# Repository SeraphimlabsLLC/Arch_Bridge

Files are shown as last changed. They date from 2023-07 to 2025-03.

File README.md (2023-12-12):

# Arch_Bridge

DCC-EX to Loconet accessory bus interface with throttle and booster driving. 

Additional 2A booster channel for future use

 Bidirectional transmission of turnout commands from Loconet to DCC-EX
 One way Throttle transmission, Loconet to DCC-EX

 Fastclock supplied to DCC-EX, still WIP getting it on Loconet

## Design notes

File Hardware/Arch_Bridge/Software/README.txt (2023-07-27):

TTY Pin Map
TXD = GPIO43(U0TXD)
RXD = GPIO44(U0RXD)

I2C Pin Map
SDA = GPIO15
SCL = GPIO16

Loconet Pin Map
LN_TX = GPIO17(U1RXD)
LN_RX = GPIO18 (U1RXD)
LN_COLL = GPIO0

Railsync input Pin Map
RSYNC_IN = GPIO9

Railsync output Pin Map
ENA_10 = GPIO10
DCC_1 = GPIO11
BRK_1 = GPIO12
ENA_1i = GPIO13
SNS1 = GPIO1(ADC1_CH0)

Track output Pin Map
ENA_20 = GPIO14
DCC_2 = GPIO21
BRK_2 = GPIO47
ENA_2i = GPIO48
SNS2 = GPIO2(ADC1_CH1)

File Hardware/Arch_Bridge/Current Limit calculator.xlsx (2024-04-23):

A | 0.2 | 0.2 | 0.2 | A | 2 | 2 | 2
SF (A per A) | 0.0015 | 0.0015 | 0.0015 | SF (A per A) | 0.0015 | 0.0015 | 0.0015
% | 0.10% |  | 0.10% | % | 0.10% |  | 0.10%
Ipropi(A) | 0.0003 | 0.0003 | 0.0003 | Ipropi(A) | 0.003 | 0.003 | 0.003
Ripropi(oh) | 9090.9 | 9100 | 9109.1 | Ripropi(oh) | 909.09 | 910 | 910.91
Vipropi(V) | 2.72727 | 2.73 | 2.73273 | Vipropi(V) | 2.72727 | 2.73 | 2.73273
vref | 3.3 | 3.3 | 3.3 | vref | 3.3 | 3.3 | 3.3
itripprpi | 0.000363000363 | 0.0003626373626 | 0.0003622750875 | itripprpi | 0.00363000363 | 0.003626373626 | 0.003622750875
Trip | 0.242000242 | 0.2417582418 | 0.241516725 | Trip | 2.42000242 | 2.417582418 | 2.41516725
Trip_Tick | 319.6745132 | 319.3548387 | 319.0358029 |  | 3196.745132 | 3193.548387 | 3190.358029
Vmax | 3.1 | 3.1 | 3.1 | Vmax | 3.1 | 3.1 | 3.1
Dmax | 4095 | 4095 | 4095 | Dmax | 4095 | 4095 | 4095
Div/V | 1320.967742 | 1320.967742 | 1320.967742 | Div/V | 1320.967742 | 1320.967742 | 1320.967742
Div/A | 16921.47068 | 16938.40909 | 16955.3475 | Div/A | 1692.147068 | 1693.840909 | 1695.53475
div/mA | 16.92147068 | 16.93840909 | 16.9553475 | Div/mA | 1.692147068 | 1.693840909 | 1.69553475
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

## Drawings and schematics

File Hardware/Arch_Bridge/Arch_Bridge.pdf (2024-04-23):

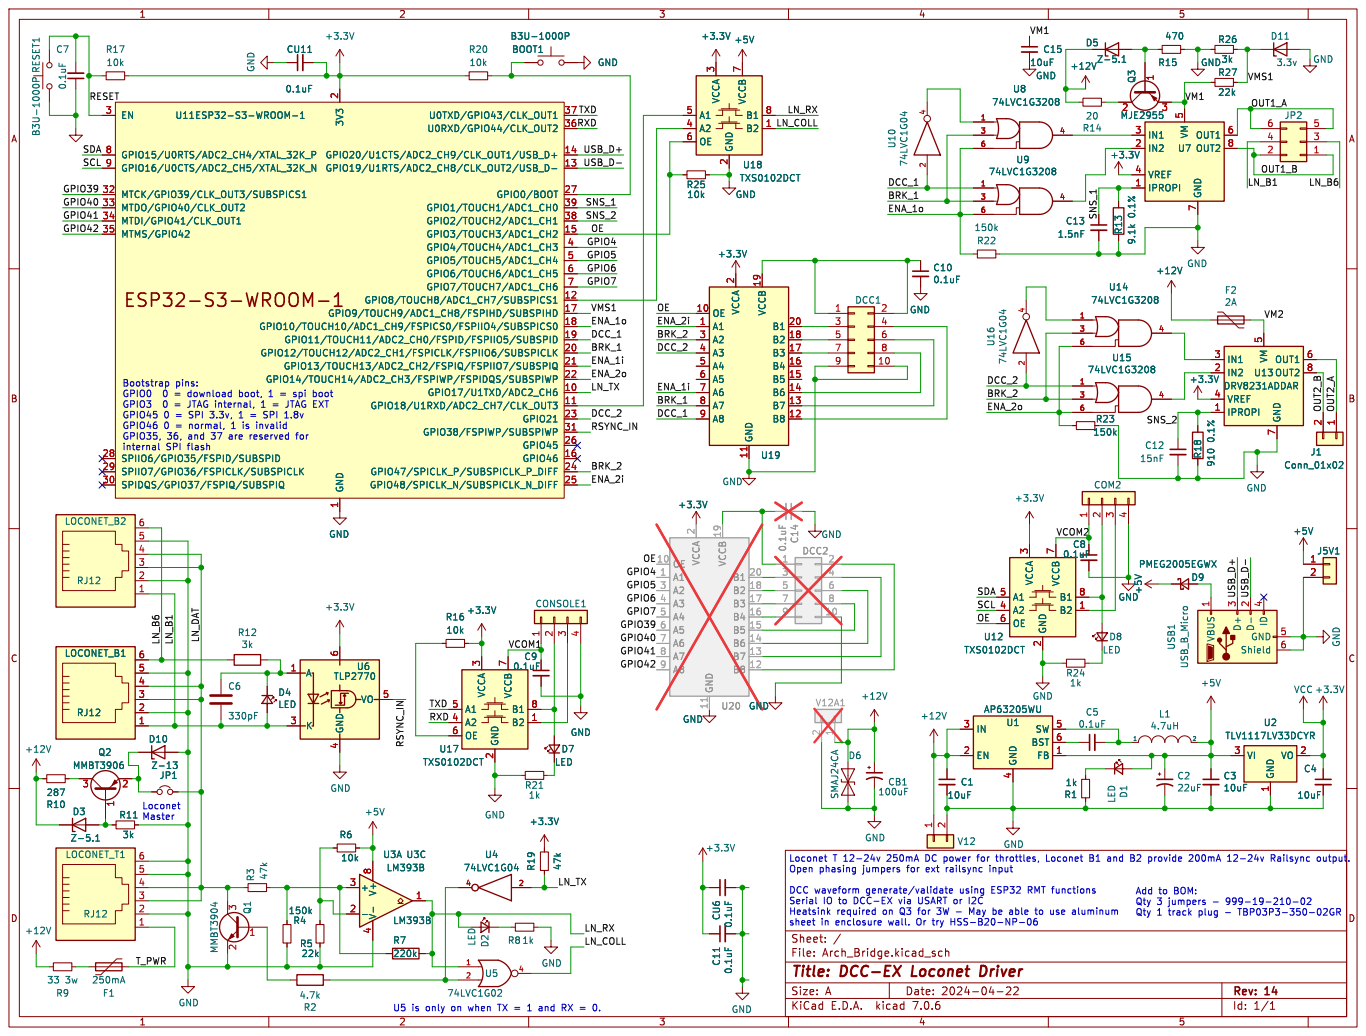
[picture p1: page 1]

2 GPIO12/TOUCH12/ADC2_CH1/FSPICLK/FSPIIO6/SUBSPICLK 20 GPIO13/TOUCH13/ADC2_CH2/FSPIQ/FSPIIO7/SUBSPIQ 21 GPIO14/TOUCH14/ADC2_CH3/FSPIWP/FSPIDQS/SUBSPIWP 22 GPIO21 23 GPIO47/SPICLK_P/SUBSPICLK_P_DIFF 24 GPIO48/SPICLK_N/SUBSPICLK_N_DIFF 25 GPIO45 26 GPIO0/BOOT 27 SPIIO6/GPIO35/FSPID/SUBSPID 28 SPIIO7/GPIO36/FSPICLK/SUBSPICLK 29 EN 3 SPIDQS/GPIO37/FSPIQ/SUBSPIQ 30 GPIO38/FSPIWP/SUBSPIWP 31 MTCK/GPIO39/CLK_OUT3/SUBSPICS1 32 MTDO/GPIO40/CLK_OUT2 33 MTDI/GPIO41/CLK_OUT1 34 MTMS/GPIO42 35 U0RXD/GPIO44/CLK_OUT2 36 U0TXD/GPIO43/CLK_OUT1 37 GPIO2/TOUCH2/ADC1_CH1 38 GPIO1/TOUCH1/ADC1_CH0 39 GPIO4/TOUCH4/ADC1_CH3 4 GPIO5/TOUCH5/ADC1_CH4 5 GPIO6/TOUCH6/ADC1_CH5 6 GPIO7/TOUCH7/ADC1_CH6 7 GPIO15/U0RTS/ADC2_CH4/XTAL_32K_P 8 GPIO16/U0CTS/ADC2_CH5/XTAL_32K_N 9 CU11

7 B1 8U19 A1 1 OE 10 GND 11 B8 12 B7 13 B6 14 B5 15 B4 16 B3 17 B2 18 VCCB 19 VCCA

2 GPIO12/TOUCH12/ADC2_CH1/FSPICLK/FSPIIO6/SUBSPICLK 20 GPIO13/TOUCH13/ADC2_CH2/FSPIQ/FSPIIO7/SUBSPIQ 21 GPIO14/TOUCH14/ADC2_CH3/FSPIWP/FSPIDQS/SUBSPIWP 22 GPIO21 23 GPIO47/SPICLK_P/SUBSPICLK_P_DIFF 24 GPIO48/SPICLK_N/SUBSPICLK_N_DIFF 25 GPIO45 26 GPIO0/BOOT 27 SPIIO6/GPIO35/FSPID/SUBSPID 28 SPIIO7/GPIO36/FSPICLK/SUBSPICLK 29 EN 3 SPIDQS/GPIO37/FSPIQ/SUBSPIQ 30 GPIO38/FSPIWP/SUBSPIWP 31 MTCK/GPIO39/CLK_OUT3/SUBSPICS1 32 MTDO/GPIO40/CLK_OUT2 33 MTDI/GPIO41/CLK_OUT1 34 MTMS/GPIO42 35 U0RXD/GPIO44/CLK_OUT2 36 U0TXD/GPIO43/CLK_OUT1 37 GPIO2/TOUCH2/ADC1_CH1 38 GPIO1/TOUCH1/ADC1_CH0 39 GPIO4/TOUCH4/ADC1_CH3 4 GPIO5/TOUCH5/ADC1_CH4 5 GPIO6/TOUCH6/ADC1_CH5 6 GPIO7/TOUCH7/ADC1_CH6 7 GPIO15/U0RTS/ADC2_CH4/XTAL_32K_P 8 GPIO16/U0CTS/ADC2_CH5/XTAL_32K_N 9 U11 ESP32-S3-WROOM-1 A

1 GPIO17/U1TXD/ADC2_CH6 10 GPIO18/U1RXD/ADC2_CH7/CLK_OUT3 11 GPIO8/TOUCH8/ADC1_CH7/SUBSPICS1 12 GPIO19/U1RTS/ADC2_CH8/CLK_OUT2/USB_D- 13 GPIO20/U1CTS/ADC2_CH9/CLK_OUT1/USB_D+ 14 GPIO3/TOUCH3/ADC1_CH2 15 GPIO46 16 GPIO9/TOUCH9/ADC1_CH8/FSPIHD/SUBSPIHD 17 GPIO10/TOUCH10/ADC1_CH9/FSPICS0/FSPIIO4/SUBSPICS0 18 GPIO11/TOUCH11/ADC2_CH0/FSPID/FSPIIO5/SUBSPID 19 3V3

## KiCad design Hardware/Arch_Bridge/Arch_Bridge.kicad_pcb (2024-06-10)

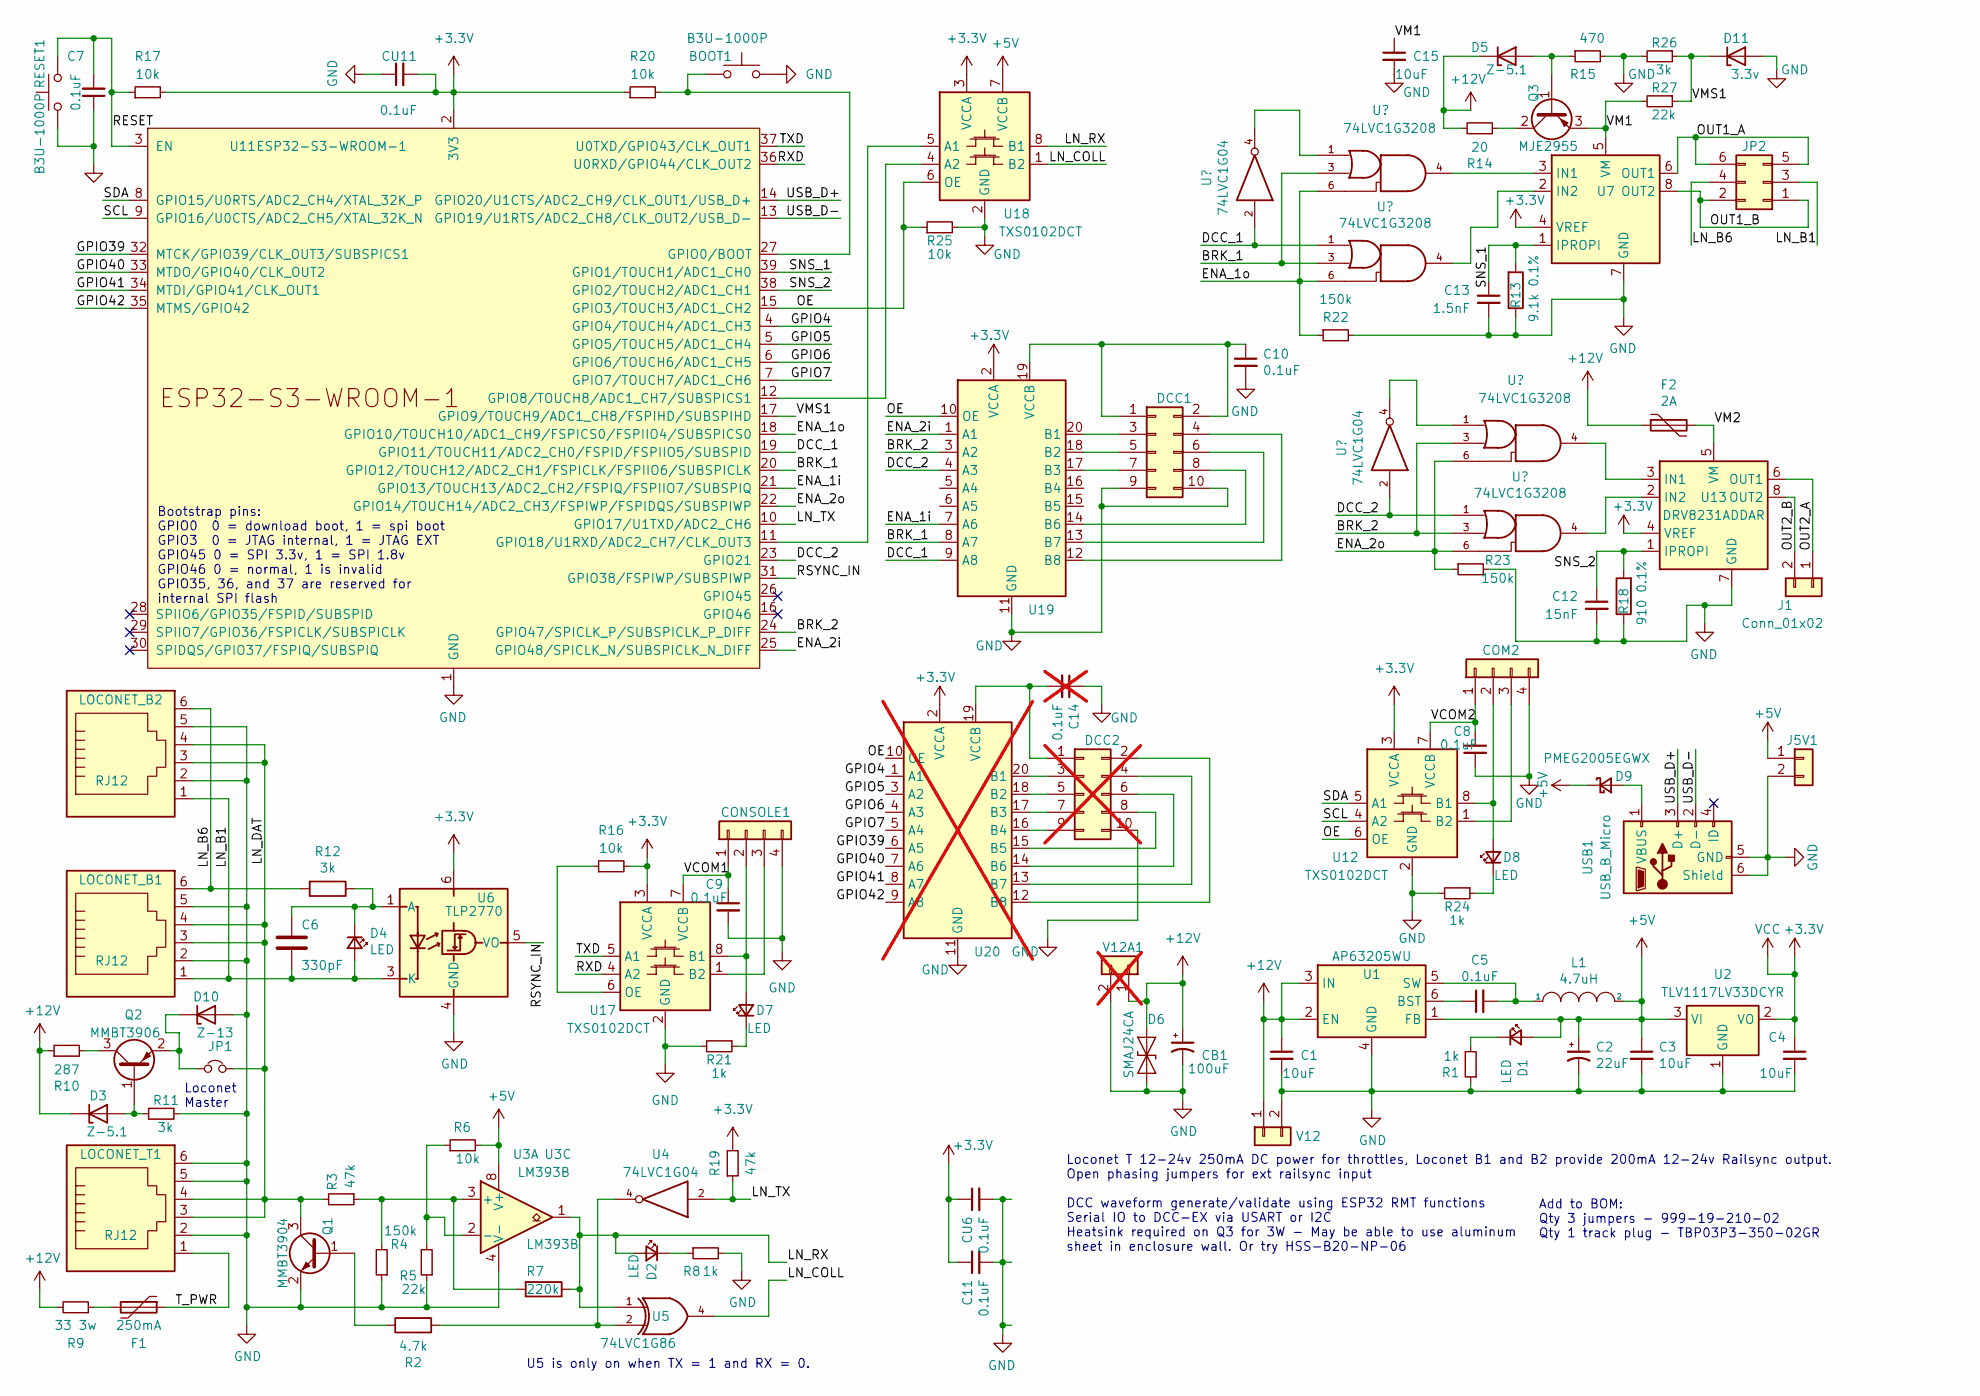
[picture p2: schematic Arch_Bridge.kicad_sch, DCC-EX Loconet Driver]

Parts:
BOOT1: B3U-1000P; SW_SPST_B3U-1000P-B; LCSC SKU C231329
C1, C3, C4, C15: 10uF; C_1210_3225Metric; LCSC SKU C380537
C2: 22uF; CP_Elec_5x5.3; LCSC SKU C2164091
C5, C7, C8, C9, C10, C11: 0.1uF; C_1206_3216Metric; LCSC SKU C600013
C6: 330pF; C_1206_3216Metric; LCSC SKU C2223641
C12: 15nF; C_1206_3216Metric_Pad1.33x1.80mm_HandSolder; LCSC SKU C2174116
C13: 1.5nF; C_1206_3216Metric_Pad1.33x1.80mm_HandSolder; LCSC SKU C2230319
C14: 0.1uF; C_1206_3216Metric; LCSC SKU C600013; not fitted
CB1: 100uF; CP_Elec_8x10; LCSC SKU C696384
COM2: Conn_01x04; PinSocket_1x04_P2.54mm_Vertical; LCSC SKU C3323964
CONSOLE1: Conn_01x04; PinSocket_1x04_P2.54mm_Vertical; LCSC SKU C3323964
CU6, CU11: 0.1uF; C_1206_3216Metric; LCSC SKU C600013
D1, D2, D4, D7, D8: LED; LED_1206_3216Metric
D3, D5: Z-5.1; D_MiniMELF; LCSC SKU C550442
D6: SMAJ24CA; D_SMA; LCSC SKU C148223
D9: PMEG2005EGWX; D_SOD-123; LCSC SKU C552812
D10: Z-13; D_MiniMELF; LCSC SKU C550391
D11: 3.3v; D_MiniMELF; LCSC SKU C550442
DCC1: Conn_02x05_Odd_Even; PinSocket_2x05_P2.54mm_Vertical; LCSC SKU C6235491
DCC2: Conn_02x05_Odd_Even; PinSocket_2x05_P2.54mm_Vertical; LCSC SKU C6235491; not fitted
F1: 250mA; Fuse_1206_3216Metric; LCSC SKU C2442492
F2: 2A; Fuse_Bourns_MF-RHT200; LCSC SKU C2153889
J1: Conn_01x02; PhoenixContact_MC_1,5_2-G-3.5_1x02_P3.50mm_Horizontal; LCSC SKU C880572
J5V1: Conn_01x02; PinSocket_1x02_P2.54mm_Vertical; LCSC SKU C3323491
JP1: Jumper_NC_Small; PinHeader_1x02_P2.54mm_Vertical; LCSC SKU C5172712
JP2: Conn_02x03_Odd_Even; PinHeader_2x03_P2.54mm_Vertical; LCSC SKU C6360273
L1: 4.7uH; L_Wurth_WE-LQSH-4020; LCSC SKU C167828
LOCONET_B1, LOCONET_B2: RJ12; RJ12_Amphenol_54601; LCSC SKU C4355015
LOCONET_T1: RJ12; RJ12_Amphenol_54601; LCSC SKU C4355015
Q1: MMBT3904; SOT-23; LCSC SKU C77991
Q2: MMBT3906; SOT-23; LCSC SKU C77990
Q3: MJE2955; TO-220-3_Vertical; LCSC SKU C184196
R1, R8, R21, R24: 1k; R_1206_3216Metric; LCSC SKU C131398
R2: 4.7k; R_1206_3216Metric; LCSC SKU C3975500
R3, R19: 47k; R_1206_3216Metric; LCSC SKU C137270
R4, R22, R23: 150k; R_1206_3216Metric; LCSC SKU C114931
R5, R27: 22k; R_1206_3216Metric; LCSC SKU C114942
R6, R16, R17, R20, R25: 10k; R_1206_3216Metric; LCSC SKU C4303232
R7: 220k; R_1206_3216Metric; LCSC SKU C130275
R9: 33 3w; R_Axial_DIN0516_L15.5mm_D5.0mm_P5.08mm_Vertical; LCSC SKU C1761032
R10: 287; R_1206_3216Metric; LCSC SKU C488764
R11, R12, R26: 3k; R_1206_3216Metric; LCSC SKU C132648
R13: 9.1k 0.1%; R_1206_3216Metric; LCSC SKU C706423
R14: 20; R_2512_6332Metric; LCSC SKU C309605
R15: 470; R_2512_6332Metric; LCSC SKU C872782
R18: 910 0.1%; R_1206_3216Metric; LCSC SKU C870936
RESET1: B3U-1000P; SW_SPST_B3U-1000P-B; LCSC SKU C231329
U1: AP63205WU; TSOT-23-6; LCSC SKU C2071056
U2: TLV1117LV33DCYR; SOT-223-3_TabPin2; LCSC SKU C91728
U3: LM393B; SOIC-8_3.9x4.9mm_P1.27mm; LCSC SKU C2865059
U4, U10, U16: 74LVC1G04; SOT-23-5_HandSoldering; LCSC SKU C7827
U5: 74LVC1G86; SOT-23-5_HandSoldering; LCSC SKU C402161
U6: TLP2770; SO-6L_10x3.84mm_P1.27mm; LCSC SKU C150160
U7, U13: DRV8231ADDAR; Texas_HTSOP-8-1EP_3.9x4.9mm_P1.27mm_EP2.95x4.9mm_Mask2.4x3.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
U8, U9, U14, U15: 74LVC1G3208; SOT-23-6_Handsoldering; LCSC SKU C2682152
U11: ESP32-S3-WROOM-1; ESP32-S3-WROOM-1U; LCSC SKU C2980298
U12, U17, U18: TXS0102DCT; SSOP-8_2.95x2.8mm_P0.65mm; LCSC SKU C2677354
U19: TXB0108PWR; TSSOP-20_4.4x6.5mm_P0.65mm; LCSC SKU C53406
U20: TXB0108PWR; TSSOP-20_4.4x6.5mm_P0.65mm; LCSC SKU C53406; not fitted
USB1: USB_B_Micro; USB_Micro-B_Molex-105017-0001; LCSC SKU C136000
V12: Conn_01x02; PhoenixContact_MSTBA_2,5_2-G_1x02_P5.00mm_Horizontal
V12A1: Conn_01x02; Screw_Terminal_2pin_Multicomp; not fitted

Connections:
+3.3V: C4.1, C11.1, CU6.1, CU11.2, R16.2, R17.2, R19.2, R20.1, U2.2 (VO), U6.6, U7.4 (VREF), U8.5 (VCC), U9.5 (VCC), U10.5 (VCC), U11.2 (3V3), U12.3 (VCCA), U13.4 (VREF), U14.5 (VCC), U15.5 (VCC), U16.5 (VCC), U17.3 (VCCA), U18.3 (VCCA), U19.2 (VCCA), U20.2 (VCCA)
+5V: C2.1, C3.1, D1.2 (A), D9.1 (K), J5V1.1, L1.2, R6.2, U1.1 (FB), U2.3 (VI), U3.8 (V+), U4.5 (+5V), U5.5 (+5V), U18.7 (VCCB)
+12V: C1.1, CB1.1, D3.1 (K), D5.1 (K), D6.1 (A1), F2.1, R9.2, R10.1, R14.2, U1.2 (EN), U1.3 (IN), V12.1, V12A1.1
/BRK_1: U8.3, U9.3, U11.20 (GPIO12/TOUCH12/ADC2_CH1/FSPICLK/FSPIIO6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), U19.8 (A7)
/BRK_2: U11.24 (GPIO47/SPICLK_P/SUBSPICLK_P_DIFF), U14.3, U15.3, U19.3 (A2)
/DCC_1: U9.1, U10.2, U11.19 (GPIO11/TOUCH11/ADC2_CH0/FSPID/FSPIIO5/S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), U19.9 (A8)
/DCC_2: U11.23 (GPIO21), U15.1, U16.2, U19.4 (A3)
/ENA_1i: U11.21 (GPIO13/TOUCH13/ADC2_CH2/FSPIQ/FSPIIO7/S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), U19.7 (A6)
/ENA_1o: R22.1, U8.6, U9.6, U11.18 (GPIO10/TOUCH10/ADC1_CH9/FSPICS0/FSPIIO4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)
/ENA_2i: U11.25 (GPIO48/SPICLK_N/SUBSPICLK_N_DIFF), U19.1 (A1)
/ENA_2o: R23.1, U11.22 (GPIO14/TOUCH14/ADC2_CH3/FSPIWP/FSPIDQS/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), U14.6, U15.6
/GPIO4: U11.4 (GPIO4/TOUCH4/ADC1_CH3), U20.1 (A1)
/GPIO5: U11.5 (GPIO5/TOUCH5/ADC1_CH4), U20.3 (A2)
/GPIO6: U11.6 (GPIO6/TOUCH6/ADC1_CH5), U20.4 (A3)
/GPIO7: U11.7 (GPIO7/TOUCH7/ADC1_CH6), U20.5 (A4)
/GPIO39: U11.32 (MTCK/GPIO39/CLK_OUT3/SUBSPICS1), U20.6 (A5)
/GPIO40: U11.33 (MTDO/GPIO40/CLK_OUT2), U20.7 (A6)
/GPIO41: U11.34 (MTDI/GPIO41/CLK_OUT1), U20.8 (A7)
/GPIO42: U11.35 (MTMS/GPIO42), U20.9 (A8)
/LN_B1: C6.2, D4.2 (A), JP2.3, LOCONET_B1.1, LOCONET_B2.1, U6.3 (K)
/LN_B6: JP2.4, LOCONET_B1.6, LOCONET_B2.6, R12.2
/LN_COLL: U5.4, U18.1 (B2)
/LN_DAT: JP1.2, LOCONET_B1.3, LOCONET_B1.4, LOCONET_B2.3, LOCONET_B2.4, LOCONET_T1.3, LOCONET_T1.4, Q1.3 (C), R3.2
/LN_RX: D2.2 (A), R7.1, U3.1, U5.1, U18.8 (B1)
/LN_TX: R19.1, U4.2, U11.10 (GPIO17/U1TXD/ADC2_CH6)
/OE: R25.1, U11.15 (GPIO3/TOUCH3/ADC1_CH2), U12.6 (OE), U18.6 (OE), U19.10 (OE), U20.10 (OE)
/OUT1_A: JP2.5, JP2.6, U7.6 (OUT1)
/OUT1_B: JP2.1, JP2.2, U7.8 (OUT2)
/OUT2_A: J1.1, U13.6 (OUT1)
/OUT2_B: J1.2, U13.8 (OUT2)
/RESET: C7.2, R17.1, RESET1.2, U11.3 (EN)
/RSYNC_IN: U6.5 (VO), U11.31 (GPIO38/FSPIWP/SUBSPIWP)
/RXD: U11.36 (U0RXD/GPIO44/CLK_OUT2), U17.4 (A2)
/SCL: U11.9 (GPIO16/U0CTS/ADC2_CH5/XTAL_32K_N), U12.4 (A2)
/SDA: U11.8 (GPIO15/U0RTS/ADC2_CH4/XTAL_32K_P), U12.5 (A1)
/SNS_1: C13.1, R13.2, U7.1 (IPROPI), U11.39 (GPIO1/TOUCH1/ADC1_CH0)
/SNS_2: C12.1, R18.2, U11.38 (GPIO2/TOUCH2/ADC1_CH1), U13.1 (IPROPI)
/TXD: U11.37 (U0TXD/GPIO43/CLK_OUT1), U17.5 (A1)
/T_PWR: F1.1, LOCONET_T1.1
/USB_D+: U11.14 (GPIO20/U1CTS/ADC2_CH9/CLK_OUT1/USB_D+), USB1.3 (D+)
/USB_D-: U11.13 (GPIO19/U1RTS/ADC2_CH8/CLK_OUT2/USB_D-), USB1.2 (D-)
/VCOM1: C9.1, CONSOLE1.1, U17.7 (VCCB)
/VCOM2: C8.1, COM2.1, U12.7 (VCCB)
/VM1: C15.1, Q3.3 (E), R27.2, U7.5 (VM)
/VM2: F2.2, U13.5 (VM)
/VMS1: D11.1 (K), R26.1, R27.1, U11.17 (GPIO9/TOUCH9/ADC1_CH8/FSPIHD/SUBSPIHD)
GND: BOOT1.1, C1.2, C2.2, C3.2, C4.2, C7.1, C8.2, C9.2, C10.2, C11.2, C12.2, C13.2, C14.1, C15.2, CB1.2, COM2.4, CONSOLE1.4, CU6.2, CU11.1, D6.2 (A2), D10.2 (A), D11.2 (A), DCC1.9, DCC1.10, DCC2.10, J5V1.2, LOCONET_B1.2, LOCONET_B1.5, LOCONET_B2.2, LOCONET_B2.5, LOCONET_T1.2, LOCONET_T1.5, LOCONET_T1.6, Q1.2 (E), R1.1, R4.1, R5.1, R8.2, R11.1, R13.1, R15.2, R18.1, R21.2, R22.2, R23.2, R24.2, R25.2, R26.2, RESET1.1, U1.4 (GND), U2.1 (GND), U3.4 (V-), U4.3 (GND), U5.3 (GND), U6.4 (GND), U7.7 (GND), U7.9 (GND), U8.2 (GND), U9.2 (GND), U10.3 (GND), U11.1 (GND), U11.40 (GND), U11.41 (GND), U12.2 (GND), U13.7 (GND), U13.9 (GND), U14.2 (GND), U15.2 (GND), U16.3 (GND), U17.2 (GND), U18.2 (GND), U19.11 (GND), U20.11 (GND), USB1.5 (GND), USB1.6 (Shield), V12.2, V12A1.2; also elsewhere on the board
unnamed: COM2.2, D8.2 (A), U12.8 (B1)
unnamed: COM2.3, U12.1 (B2)
unnamed: CONSOLE1.2, D7.2 (A), U17.8 (B1)
unnamed: CONSOLE1.3, U17.1 (B2)
unnamed: D1.1 (K), R1.2
unnamed: D2.1 (K), R8.1
unnamed: D3.2 (A), Q2.1 (B), R11.2
unnamed: C6.1, D4.1 (K), R12.1, U6.1 (A)
unnamed: D5.2 (A), Q3.1 (B), R15.1
unnamed: D7.1 (K), R21.1
unnamed: D8.1 (K), R24.1
unnamed: D9.2 (A), USB1.1 (VBUS)
unnamed: D10.1 (K), JP1.1, Q2.2 (E)
unnamed: C10.1, DCC1.1, DCC1.2, U19.19 (VCCB)
unnamed: DCC1.3, U19.20 (B1)
unnamed: DCC1.4, U19.12 (B8)
unnamed: DCC1.5, U19.18 (B2)
unnamed: DCC1.6, U19.13 (B7)
unnamed: DCC1.7, U19.17 (B3)
unnamed: DCC1.8, U19.14 (B6)
unnamed: C14.2, DCC2.1, U20.19 (VCCB)
unnamed: DCC2.2, U20.12 (B8)
unnamed: DCC2.3, U20.20 (B1)
unnamed: DCC2.4, U20.13 (B7)
unnamed: DCC2.5, U20.18 (B2)
unnamed: DCC2.6, U20.14 (B6)
unnamed: DCC2.7, U20.17 (B3)
unnamed: DCC2.8, U20.15 (B5)
unnamed: DCC2.9, U20.16 (B4)
unnamed: F1.2, R9.1
unnamed: Q1.1 (B), R2.1
unnamed: Q2.3 (C), R10.2
unnamed: Q3.2 (C), R14.1
unnamed: R2.2, U4.4, U5.2
unnamed: C5.1, U1.6 (BST)
unnamed: C5.2, L1.1, U1.5 (SW)
unnamed: R3.1, R4.2, R7.2, U3.3 (+)
unnamed: R5.2, R6.1, U3.2 (-)
unnamed: U7.3 (IN1), U8.4
unnamed: U7.2 (IN2), U9.4
unnamed: U8.1, U10.4
unnamed: BOOT1.2, R20.2, U11.27 (GPIO0/BOOT)
unnamed: U11.12 (GPIO8/TOUCH8/ADC1_CH7/SUBSPICS1), U18.4 (A2)
unnamed: U11.11 (GPIO18/U1RXD/ADC2_CH7/CLK_OUT3), U18.5 (A1)
unnamed: U13.3 (IN1), U14.4
unnamed: U13.2 (IN2), U15.4
unnamed: U14.1, U16.4
unnamed: R16.1, U17.6 (OE)

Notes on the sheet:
Loconet T 12-24v 250mA DC power for throttles, Loconet B1 and B2 provide 200mA 12-24v Railsync output. Open phasing jumpers for ext railsync input DCC waveform generate/validate using ESP32 RMT functions Serial IO to DCC-EX via USART or I2C Heatsink required on Q3 for 3W - May be able to use alumin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
U5 is only on when TX = 1 and RX = 0.
Loconet Master
Add to BOM: Qty 3 jumpers - 999-19-210-02 Qty 1 track plug - TBP03P3-350-02GR
Bootstrap pins: GPIO0 0 = download boot, 1 = spi boot GPIO3 0 = JTAG internal, 1 = JTAG EXT GPIO45 0 = SPI 3.3v, 1 = SPI 1.8v GPIO46 0 = normal, 1 is invalid GPIO35, 36, and 37 are reserved for internal SPI flash

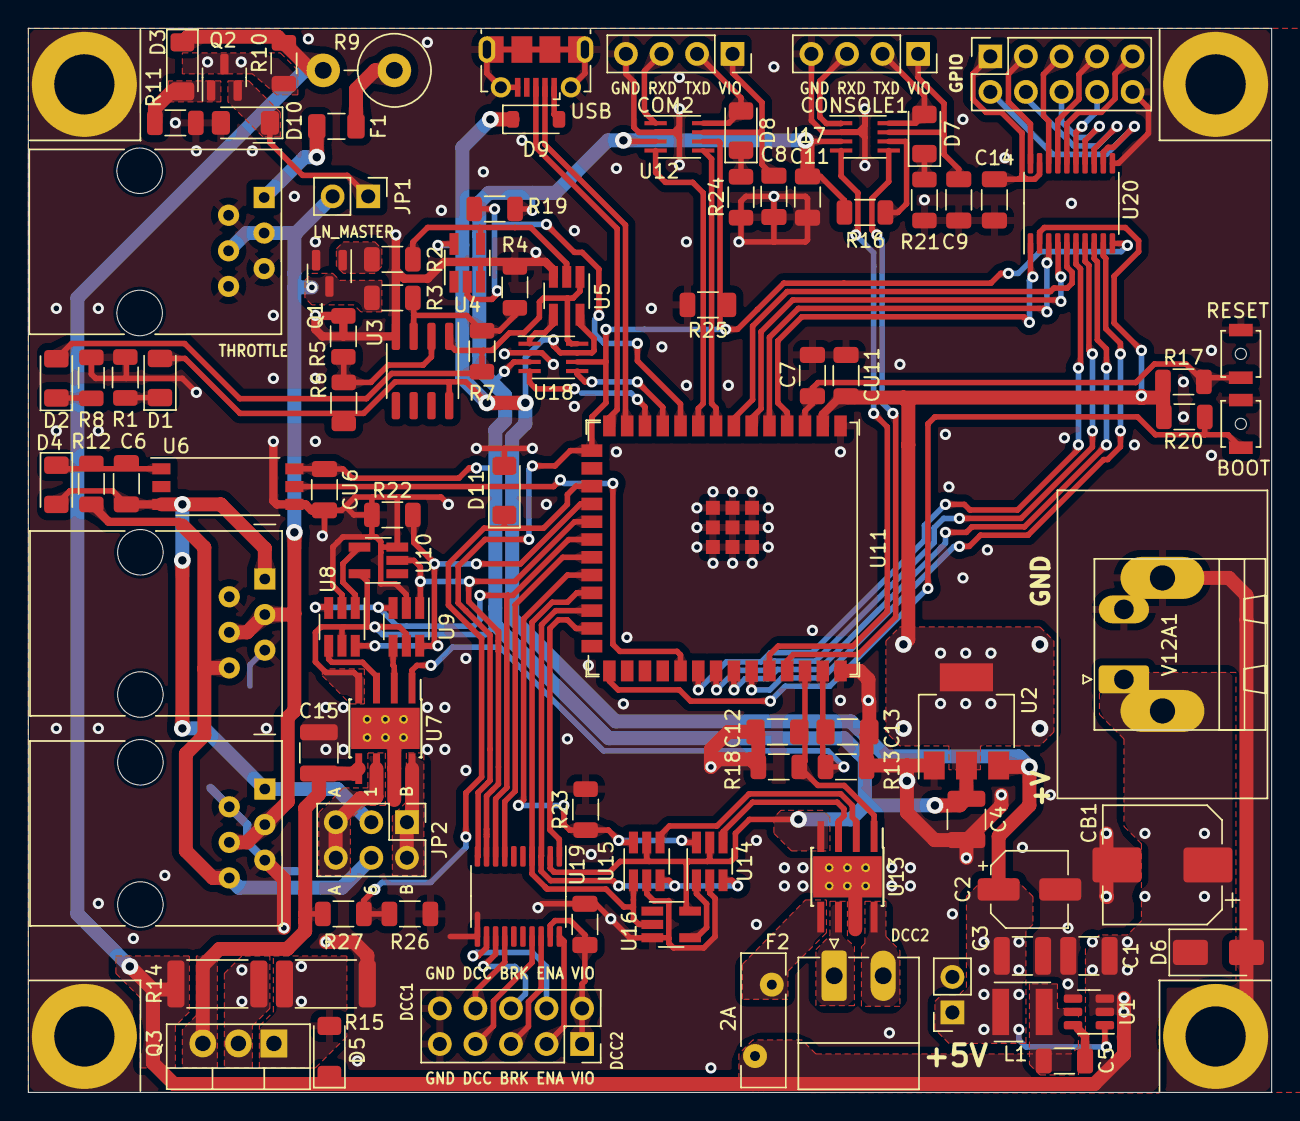
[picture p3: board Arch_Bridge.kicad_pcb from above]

Board: 2 copper layers, 88.8 x 76.0 mm, 101 parts (0 on the bottom side), 95 nets.

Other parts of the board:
H1, H2, H4: MountingHole_Pad; MountingHole_4.3mm_M4_DIN965_Pad

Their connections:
GND: H1.1, H2.1, H4.1; also elsewhere on the board

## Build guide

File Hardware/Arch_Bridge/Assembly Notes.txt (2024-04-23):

Could decrease R9 from 5w to 3w if staying at 500mA fuse, since it would never see more than 2.5W.
Changed in Rev 06: R9 33 ohm 2w, F2 changed to 250mA.

Q2 badly underperforming, HFE showing as only 11 when datasheet minimum says 20.
Load is only 114mW, perhaps switch to a 2N2907?
Alternatively, R10 to 270 ohms and R11 to 4.7kohm   Yaego RC1206FR-10270RL and RC1206FR-104K7L
Better, change only R11 to 3k using RC1206FR-073KL << Worked perfectly, 14.5mA on 12.8v input
Fixed in Rev 06.

Q3 is also badly underperforming. HFE measured at only 13 again for datasheet minimum of 20.
Could try changing R15 to 470 ohms, giving 208mA.
Fixed in Rev 06.

Original PCB contains a mistake in U18, the 5v and 3.3v sides of the chip are reversed. Somehow the ESP seems ok with this.
Fixed in Rev 06.

Reassign UART0 to be labelled Console, and bring boot and reset to the header to work with cts and rts automation.
Rev 06 changes label and pinout. Did not bring CTS or RTS. 

DCC-EX TTY should be on uart2 since LN uses 1. The CS doesn't want to deal with debug and could crash.
Rev 06 changes label and pinout.

Falstead Simulation:
https://www.falstad.com/circuit/circuitjs.html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

PCB Rev 10: 
Revised VIN to 5v power supply using MLCC instead of Electrolytic for smoother output and smaller footprint.
Found that the H bridges shut down in UVLO trip if the input voltage to them is under 4v. 

Rev 14:

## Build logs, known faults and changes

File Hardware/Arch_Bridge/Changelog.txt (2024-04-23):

Rev 06:
Decreased F2 250mA fuse, making it same as F1.
R9 is now 33 ohm 2w, voltage drops below 7v triggering limiting/disconnect before F2 blows.
Previous design would have blown fuse above 12v before railsync devices disconnected. 

Relabel TTY to CONSOLE. 
Changed pinout to match Crystal board: +5v, TX, RX, GND. 
Added status LED on TX. 

Relabel I2C to COM2. 
Changed pinout: +5v, TX, RX, GND.
Added status LED on TX. 
Connected OE to processor OE output. 

PCB revision to incorporate these changes.

Rev 06A: 
Changed CB1 to through hole for field installation. Removed from default bom and populate.

Rev 11:
Found R15 would overheat if >12v was used.
Changed R14 and R15 to be 2512 SMD resistors for 1w heat capacity, allowing vin up to 24v

Also moved CB1 to be closer to vreg, and repositioned CB2 to be closer to ESP. Although optional, these bulk caps may be needed for stabilization.

Rev 12:
Changed Q1 to MMBT3904 in SOT23
Changed Q3 to MMBT3906 in SOT23
Added D10, a 12v zener diode to limit Loconet Master current source voltage. May change to a 13v zener to allow a little more driving margin.
Changed D3 and D5 to SMD instead of THT.

Rev 14:
Restructured H bridge logic gating to run on 3.3v, revised layout for better board space usage.
Loconet RX and TX using ICs U3, U4, and U5 are still 5v. 
Level shifters for DCC driving, CONSOLE1, and COM2 now have independent IOREF inputs
Put CB1 back to SMD and included in BOM.
Added voltage divider to monitor Railsync H bridge voltage and warn if below 7v. H bridge UVLO trips at 4v. 
Added C15 to prevent fluctuations in the Railsync H bridge.

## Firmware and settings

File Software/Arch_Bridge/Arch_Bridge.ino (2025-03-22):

//Use config.h if present, otherwise defaults
#ifndef CONFIG_H
  #if __has_include ("config.h")
    #include "config.h"
  #endif
  #ifndef CONFIG_H
    #include "config.example.h"
  #endif
#endif  
#ifndef ESP32_UART_H
  #include "ESP32_uart.h"
#endif
#ifndef ESP32_ADC_H
  #include "ESP32_adc.h"
#endif
#ifndef ESP32_RMTDCC_H
  #include "ESP32_rmtdcc.h"
#endif
#ifndef DCC_READ_H
  #include "dcc_read.h"
#endif

#ifndef ESP32_TRACKS_HW_H
  #include "ESP32_Tracks_HW.h"
#endif
#ifndef ESP32_DCCEX_H
  #include "ESP32_dccex.h"
#endif  

#ifndef ESP32_TIMER_H
  #include "ESP32_timer.h"
#endif

#if BOARD_TYPE == ARCH_BRIDGE //If this is an arch bridge, include loconet functions
  #ifndef ESP32_LOCONET_H
    #include "ESP32_Loconet.h"
  #endif
#endif

//extern TrackChannel DCCSigs[];
//extern Rmtdcc dcc; 
TaskHandle_t loop_task;

volatile uint64_t edge_last;
volatile uint32_t edge_delta;
volatile uint8_t edge_stream; 
volatile uint8_t edge_count;

void IRAM_ATTR dir_monitor_isr(){
  edge_delta = TIME_US - edge_last;
  edge_last = TIME_US;
  edge_count++;
  edge_stream = edge_stream << 1; //bit shift one left
  edge_stream = edge_stream + gpio_get_level(gpio_num_t(9));
  if ((edge_delta > DCC_1_MIN_HALFPERIOD) && (edge_delta < DCC_1_MAX_HALFPERIOD)) {
    edge_stream = edge_stream << 1; //bit shift one let
    edge_stream = edge_stream + 1; 
  }
  if ((edge_delta > DCC_0_MIN_HALFPERIOD) && (edge_delta < DCC_0_MAX_HALFPERIOD)) {
    edge_stream = edge_stream << 1; //bit shift one left
    edge_stream = edge_stream + 0; 
  } 
  return;
}

void setup() {

  ESP_uart_init(); //Initialize tty
 delay(1000); //delay by 1000mS so the USB console starts first
  dccex_init(); //Initialize DCCEX parser
  dccrx_init(); //Initialize DCC signal audit
//  attachInterrupt(8, dir_monitor_isr, CHANGE);
  Tracks_Init();  //Initialize GPIO 
 

  #if BOARD_TYPE == ARCH_BRIDGE
    LN_init(); //Initialize Loconet
    Fastclock_setup(FCLK_ACTIVE); //Check fastclock settings and start it      
  #endif
  ADC_Setup_Commit(); //Run last in setup() to commit the ADC config built up by everything else and start the sampler
  Serial.print("Setup Complete \n");  
   xTaskCreatePinnedToCore(loop_Task, "loopTask", 10000, NULL, 1, &loop_task, 1); 
}

void loop() { 
  //delay(163840); //can't stop loop(), but can make it block.
}

void loop_Task(void * pvParameters) {
  while (true) {
#if ADC_TASK != TRUE
//  ADC_loop(); //Process ADC data, now in its own task
#endif
dccex_loop(); //Process serial input for DCCEX commands
Tracks_Loop(); //Process and update tracks
//dccrx_loop(); //Process and update DCC packets

#if BOARD_TYPE == ARCH_BRIDGE //If this is an arch bridge, check the loconet

  LN_loop(); //Process Loconet loop
  
#endif 
Heartbeat(HEARTBEAT_S);
  }
}

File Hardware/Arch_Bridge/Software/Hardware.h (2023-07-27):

//ADC Settings:
#DEFINE ADC_DMAX 4095 //4095 in single shot, 8191 in continuous
#DEFINE ADC_VMAX 3.1 //Max readable voltage is actually 3.1v using mode ADC_ATTEN_DB_11  

//TTY settings:
/* Pin Map
TXD = GPIO43(U0TXD)
RXD = GPIO44(U0RXD)
*/
#DEFINE TTY_TX_BUFF = 4096
#DEFINE TTY_RX_BUFF = 4096

//I2C settings: 
/* Pin Map
SDA = GPIO15
SCL = GPIO16
*/
#DEFINE I2C_TX_BUFF = 4096
#DEFINE I2C_RX_BUFF = 4096

//Loconet settings:
/* Pin Map
LN_TX = GPIO17(U1RXD)
LN_RX = GPIO18 (U1RXD)
LN_COLL = GPIO0
*/
#DEFINE LN_TX_BUFF = 4096
#DEFINE LN_RX_BUFF = 4096

//Railsync input settings:
/* Pin Map
RSYNC_IN = GPIO9
*/

//Railsync output settings:
/*  Pin Map
ENA_10 = GPIO10
DCC_1 = GPIO11
BRK_1 = GPIO12
ENA_1i = GPIO13
SNS1 = GPIO1(ADC1_CH0)
*/
#DEFINE OUT1_MAX_A 3610 //ADC_DMAX / ADC_VMAX * SENSE_V for 200mA + 0.1%

//Track output settings:
/* Pin Map
ENA_20 = GPIO14
DCC_2 = GPIO21
BRK_2 = GPIO47
ENA_2i = GPIO48
SNS2 = GPIO2(ADC1_CH1)
*/
#DEFINE OUT2_MAX_A 3610 //ADC_DMAX / ADC_VMAX * SENSE_V for 2A + 0.1%

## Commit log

2023-07-27 Folder structure for hardware/software and KiCad solution
    [Arch_Bridge.kicad_pcb, Arch_Bridge.kicad_sch]
2023-07-30 Completed BOM, PCB layout cleanup, starting software.
    [Arch_Bridge.kicad_pcb, Arch_Bridge.kicad_sch, Current Limit calculator.xlsx]
2023-07-30 Add PDF schematic
2023-08-20 Revised L1 for possible 2A output, cleaner fill zones, fabrication outputs
    [Arch_Bridge-B_Cu.gbr, Arch_Bridge-B_Mask.gbr, Arch_Bridge-B_Paste.gbr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]
2023-08-21 BOM Cleanup, substitute 3.3v LDO for easier to get part.
    [Arch_Bridge.kicad_sch]
2023-08-27 Update .gitignore
    Ignore KiCad backups
2023-09-28 Added .gitignore
    [Arch_Bridge.kicad_pcb]
2023-09-28 First build using this hardware for software development.
    [Arch_Bridge.kicad_sch]
2023-09-29 ESP_Uart class added, has problems still and Arduino Serial library acting as a placeholder.
2023-09-29 Prep to move uart code and loconet code into separate files
2023-09-29 Rough split of uart code into its own files
2023-10-03 Power modes partially implemented. Railsync output H bridge handled a test waveform correctly.
    [Arch_Bridge.kicad_sch, Current Limit calculator.xlsx]
2023-10-09 ADC testing, progress reading from Loconet.
    [Arch_Bridge.kicad_sch]
2023-10-12 Progress on Loconet parser
    [Arch_Bridge.kicad_sch]
2023-10-16 Loconet RX/TX still not working.
    [Arch_Bridge.ino, ESP32_Loconet.cpp, ESP32_Loconet.h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]
2023-10-16 Loconet uart is able to send data, but still needs transmission rules
2023-10-16 Loconet UART working in both RX and TX. Can finally write the parsers.
2023-10-21 Fixed R11 value, 33k => 3k so that Q2 sources correctly. Tested at 14.5mA on a 12v supply.
    [Arch_Bridge.kicad_sch]
2023-10-22 Adjusted R15 value and ADC code to make railsync current source work correctly. 0-208mA availabe.
    [Arch_Bridge.kicad_sch, Current Limit calculator.xlsx]
2023-11-05 Moved track handling loop into its own function in ESP_Tracks.cpp. RMT RX startup implemented, still needs read functions.
2023-11-08 New classes for Loconet Packets and Loconet Slots. Significant layout of logic flow in preparation for a rewrite of Loconet transmission.
2023-11-10 TX Packet mostly works, RX scan not working properly.
    [Arch_Bridge.ino, ESP32_Loconet.cpp, ESP32_Loconet.h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]
2023-11-13 Loconet rx and tx packet handling mostly working, has some crashes. Begin framing RMT
    [Arch_Bridge.ino, ESP32_Loconet.cpp, ESP32_Loconet.h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]
2023-11-14 DCC bits to packets, temporarially using Arduino RMT library
2023-11-16 Success at last getting config.example.h to work, __has_include wasn't working. Cleaned up main, remnants of ring buffers in uart, and laid out the dccex parser
2023-11-17 Console parser input possible. Loconet still erratic/crashing.
    [ESP32_Loconet.cpp, ESP32_Loconet.h, ESP32_Tracks_HW.cpp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]
2023-11-20 Fixed Uart read issue in ESP32_Uart.cpp. Attempt at Fastclock handler in ESP32_timer so that it is accessible outside loconet too.
    [Arch_Bridge.ino, ESP32_Loconet.cpp, ESP32_Loconet.h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]
2023-11-26 TX Loopback still has problems
    [Arch_Bridge.ino, ESP32_Loconet.cpp, ESP32_Loconet.h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]
2023-11-28 Schematic rev 06 with PCB updates. Needs BOM and Fabs reprocessed.
    [Arch_Bridge-B_Cu.gbr, Arch_Bridge-B_Mask.gbr, Arch_Bridge-B_Paste.gbr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]
2023-12-04 Fixed Loconet packet processing. Fault was in packet size handling. TX confirmation by loopback works.
    [ESP32_Loconet.cpp, ESP32_Loconet.h, ESP32_Tracks_HW.cpp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]
2023-12-05 Loconet slot manager successfully accepting throttle inputs. Still needs bridging to DCC-EX.
2023-12-05 Cleaning up slot handling, connecting output to DCCEX
2023-12-09 Throttle commands from Loconet to DCC-EX working. Still need opposite direction.
2023-12-09 Changed calculation of frac_mins in Loconet fastclock handling. Will still drift relative to a DCS100.
    [ESP32_Loconet.cpp, ESP32_dccex.cpp, ESP32_timer.cpp]
2023-12-10 Cleaned up uart code, removed unnecessary tx buffer
2023-12-12 Attempt to send DCC-EX throttle changes back to Loconet throttles
2023-12-17 Changed CB1 to through hole for field installaion, no longer in BOM or populated by default.
    [Arch_Bridge.kicad_pcb, Arch_Bridge.kicad_sch]
2023-12-17 Added tags for JLCPCB Fabricaton
    [Arch_Bridge.kicad_pcb]
2023-12-22 More predictable Loconet TX_Q speeds. RX_Q similarly optimized, but continues to show high mS spike. Crashes on collision detect.
    [Arch_Bridge-B_Cu.gbr, Arch_Bridge-B_Mask.gbr, Arch_Bridge-B_Paste.gbr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]
2023-12-22 Split DCC bit processing and parsing into dcc_read.cpp and dcc_read.h. Added temporary pcint based detector since RMT continues to not work.
    [Arch_Bridge.ino, ESP32_Loconet.cpp, ESP32_Tracks_HW.cpp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]
2023-12-23 DCC signal detection operational. Packets are not actually parsed, but are assembled and checksum calculated. Touchd up track mode, power, and check enable.
2023-12-24 Reworked TrackChannel::StateChange to use - values for overload, 0 for off, +1 for on_fwd, and +2 for on_rev
    [ESP32_Tracks_HW.cpp, config.example.h]
2023-12-24 Changed ADC calculations to be x1000 instead of x1000000 so the values fit int32_t instead of int64_t.
    [Current Limit calculator.xlsx]
2023-12-29 Fixed DCC-EX track manager syntax to correctly work with text mode labels.
    [ESP32_Tracks_HW.cpp, ESP32_dccex.cpp]
2023-12-31 Schematic rev 0.8, PCB update adding current sense filter caps, fixing pull-up on Loconet TX, and slight reposition of U17
    [Arch_Bridge-B_Cu.gbr, Arch_Bridge-B_Mask.gbr, Arch_Bridge-B_Paste.gbr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]
2023-12-31 Schematic rev 0.8, fixed teardrops
    [Arch_Bridge-B_Cu.gbr, Arch_Bridge-B_Mask.gbr, Arch_Bridge-B_Paste.gbr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]
2024-01-10 Changed aux track output to use 5.0mm pitch matching EX-8874 track plugs
    [Arch_Bridge-B_Cu.gbr, Arch_Bridge-B_Mask.gbr, Arch_Bridge-B_Paste.gbr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]
2024-01-10 Forgot to add pad teardrops again.
    [Arch_Bridge-B_Cu.gbr, Arch_Bridge-B_Mask.gbr, Arch_Bridge-B_Paste.gbr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]
2024-01-14 Revised VIN to 5v power supply for better performance and less PCB space
    [Arch_Bridge-B_Cu.gbr, Arch_Bridge-B_Mask.gbr, Arch_Bridge-B_Paste.gbr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]
2024-01-14 Relocated aux output for better cooling
    [Arch_Bridge-B_Cu.gbr, Arch_Bridge-B_Mask.gbr, Arch_Bridge-B_Paste.gbr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]
2024-01-16 Fixed bug in TX_Loopback() that was causing crash. TX cooldown now uses a PCINT + timestamp for more reliable detection of network state.
    [ESP32_Loconet.cpp, ESP32_Loconet.h, ESP32_timer.cpp]
2024-01-30 BOM fix, replace NCP1117 with TLV1117
    [Arch_Bridge.kicad_sch]
2024-03-21 R15 could overheat, changed R14 and R15 to 2512 package SMDs for 1w thermal and simplified assembly. PCB rev 11. Also debugging of Loconet TX delay and throttle/turnout commands
    [Arch_Bridge.kicad_pcb, Arch_Bridge.kicad_sch]
2024-03-22 Fixed turnout address calculation, fixed disconnect detection
    [ESP32_Loconet.cpp, ESP32_Loconet.h, ESP32_dccex.cpp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]
2024-04-16 Revised PCB to fix thermal problems, improve usage of board space. DCC inputs, serial ports, and GPIO all have independent IOREF connections.
    [Arch_Bridge-B_Cu.gbr, Arch_Bridge-B_Mask.gbr, Arch_Bridge-B_Paste.gbr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]
2024-04-22 Board revision progress
    [Arch_Bridge.kicad_pcb, Arch_Bridge.kicad_sch]
2024-04-22 Fixed bug turning off enable out
    [ESP32_Tracks_HW.cpp]
2024-04-23 Added Railsync voltage monitoring circuit, stabilizer cap. Updated BOM with new parts.
    [Arch_Bridge-B_Cu.gbr, Arch_Bridge-B_Mask.gbr, Arch_Bridge-B_Paste.gbr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]
2024-04-23 Schematic update to match PCB r.14
2024-04-23 Replaced TXS0108E with TXB0108 to make use of auto-off feature when ioref is not powered
    [Arch_Bridge.kicad_sch]
2024-04-24 ESP32-dccex rx_scanrejects packets above 255 chars length
2024-06-10 Fixed BOM error for JP2, should have been 2x3 pin header not socket.
    [Arch_Bridge.kicad_pcb, Arch_Bridge.kicad_sch]
2024-06-11 Conversion to ESP32 Core 3.0 (IDF 5.1). ADC does not work, incomplete restructuring to continuous mode.
    [Arch_Bridge.ino, ESP32_Loconet.cpp, ESP32_Loconet.h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]
2024-06-11 IDF5.1: ADC not working, continuous ADC config possible.
    [ESP32_adc.cpp, ESP32_adc.h]
2024-06-14 ADC inoperative, continuous read ISR incomplete
2024-06-14 Slot 127 data populated, currently fixed values only.
    [ESP32_Loconet.cpp, ESP32_Loconet.h, ESP32_adc.cpp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]
2024-06-28 slot 127 changes
2024-06-28 ADC Continuous config present, no callback
2024-06-29 ADC Continuous enabled, no ISR or output yet
2024-06-30 ADC Continuous enabled, fixed <c> display, no ISR or data yet
    [Arch_Bridge.ino, ESP32_Loconet.cpp, ESP32_Loconet.h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]
2024-06-30 Fixed ADC setup structure to more reliably pass necessary data. Still no usable output
    [ESP32_Loconet.cpp, ESP32_Tracks_HW.cpp, ESP32_adc.cpp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]
2024-07-18 ADC runs but doesn't read properly.
    [Arch_Bridge.ino, ESP32_Loconet.cpp, ESP32_adc.cpp]
2024-07-21 Loconet host mode enum for restricting commands. Layout power command processing from Loconet to DCC-EX and back partially working.
2024-07-21 Loconet power on/off repeats to DCCEX. Known bug where you have to hit off twice for it to actually shut off.
    [ESP32_Loconet.cpp, ESP32_dccex.cpp, config.example.h]
2024-07-21 Loconet <=> DCCEX power and estop working
2024-08-28 Loconet transmit break using micros() timer \n
2024-10-13 Checkpoint before making changes to get hardware timers
2024-10-16 Added volatile flag byte for transmit active and received break so the pin change ISR can notify the loop
2024-11-08 Bugfix: Console commands are no longer parsed twice. Restructured dccex parser data input slightly. \n
    [ESP32_dccex.cpp]
2024-12-05 ADC as a separate task, but using analogRead again.
2024-12-05 Overload handling and power state/mode mutex implemntation \n
2024-12-20 Notes on ADC Continuous to try repairing it with
2024-12-31 ADC Continuous partially working
2024-12-31 ADC Continuous Read operational at last.
2024-12-31 ADC Continuous Read operational at last. Increased ADC sample rate to 30khz
2025-01-25 Converted to Arduino ESP core 3.1, aka IDF 5.3
2025-03-22 Corrected Loconet timer control issue
    [Arch_Bridge.ino, ESP32_Loconet.cpp, ESP32_Loconet.h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]
